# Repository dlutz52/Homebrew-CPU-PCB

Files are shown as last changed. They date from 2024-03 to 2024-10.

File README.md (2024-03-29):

# Homebrew CPU Project PCB

My inspiration for this PCB came from following Ian Ward's project on his web site:

[20xt6 Homebrew CPU Project](https://excess.org/cpu/)

This PCB implements the [LCD Character Display: Milestone 1 Complete!](https://www.youtube.com/watch?v=neW9uogt1gw) stage of this series of videos. 

But there is more to come in the future, so checkout Ian's videos on his future plans:

[Discrete Logic Rhythm Game Prototype (no CPU)](https://www.youtube.com/watch?v=yo5xX4GLc_U)

[Designing a Rhythm Game: Homebrew CPU Plan Step 2](https://www.youtube.com/watch?v=taPa7SQpib4)

[Maze Game Prototype (no CPU!)](https://www.youtube.com/shorts/fGyHHWiAYDM)

I will try to keep up with him.

PCB Front Image
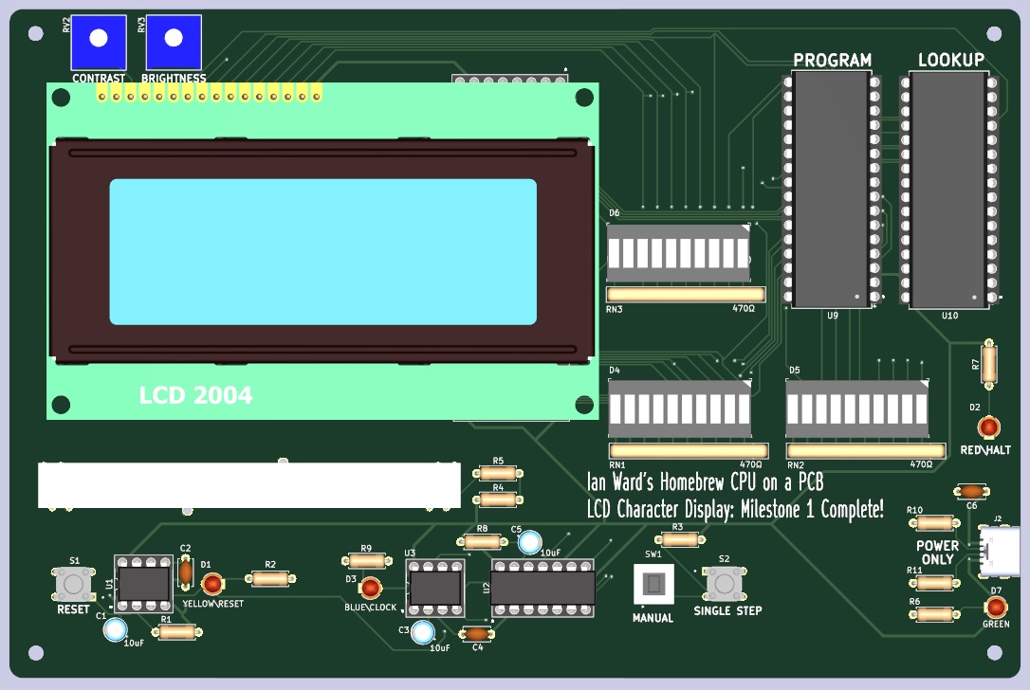
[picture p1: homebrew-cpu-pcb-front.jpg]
PCB Front Image


PCB Back Image
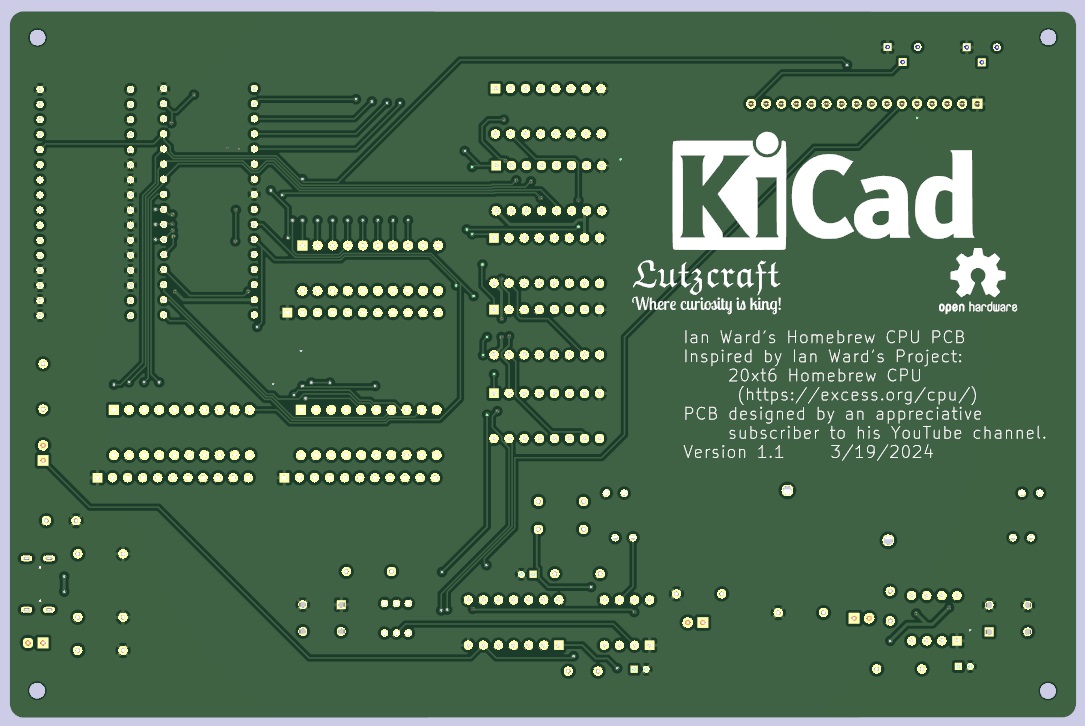
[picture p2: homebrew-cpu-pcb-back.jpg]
PCB Back Image


# Homebrew CPU PCB BOM

## Wed, Mar 21, 2024, 08:58:15

## Component Count: 25

Ref | Qty | Value | Vendor\Part # | Description
----|-----|-------|---------------|-----------
C1, C3, C5 | 3 | 10uF | Generic | Electrolytic capacitor
C2, C4, C6 | 2 | .01uF | Digikey\FG28C0G1H103JNT06 | Unpolarized capacitor 
D1 | 1 | YELLOW\Reset | Generic | LED\3mm\Yellow
D2 | 1 | RED\HALT | Generic | LED\3mm\Red 
D3 | 1 | BLUE\CLOCK | Generic | LED\3mm\Blue
D4, D5 | 2 | 10_SEG_LED BAR_GRAPH (Blue) | Digikey\1497-1079-5-ND | LED Bar Graph\Blue\1x10 
D6 | 1 | 10_SEG_LED  BAR_GRAPH (Yellow) | Digikey\754-1179-5-ND | LED Bar Graph\Yellow\1x10 
D7 | 1 | GREEN | Generic | LED\3mm\Green 
J1 | 1 | PinSocket_1x16_P2.54mm_Vertical | Generic | Female Pin Header\1x16\2.54mm pitch
J2 | 1 | UJC-HP-M-G-5-MSMT-TR | Digikey\2223-UJC-HP-M-G-5-MSMT-TRDKR-ND | Type C/20 VDC/3A/Horizontal/6 Pin/Power Only
R1, R3, R8 | 3 | 1Kohm | Digikey\13-MFR-25FTE52-1KCT-ND | Resistor\1Kohm\1%\1/4W\Axial
R2, R6, R7, R9 | 4 | 330ohm | Digikey\13-MFR-25FRF52-330RCT-ND | Resistor\330ohm\1%\1/4W\Axial
R4 | 1 | 220ohm | Generic | Resistor\220ohm\1%\1/4W\Axial
R5 | 1 | 3ohm | Generic | Resistor\3ohm\1%\1/4W\Axial
R10, R11 | 2 | 5.1Kohm | Digikey\13-MFR-25FTE52-5K1CT-ND | Resistor\5K1ohm\1%\1/4W\Axial
RN1, RN2, RN3 | 3 | 470ohm | Digikey\4609X-101-471LF-ND | Resistor Array\8 Resistors\470ohm\9SIP
RV1 | 1 | 10Kohm | Jameco\2276439 | Panasonic EWAQ30C15A14 Audio Slide Pot
RV2, RV3 | 2 | 5Kohm | Digikey\3386P-1-502LF | Trimmer Pot\5Kohms\0.5W\1/2W\Through Hole
SW1 | 1 | TL2230 | Digikey\EG6031-ND | Switch\Pushbutton\DPDT\Through Hole
S1 | 1 | REG SELECT | Digikey\450-1654-ND | Switch\Tactile\SPST-NO\0.05A\24V\Through Hole
S2 | 1 | ENABLE | Digikey\450-1654-ND | Switch\Tactile\SPST-NO\0.05A\24V\Through Hole
U1, U3 | 2 | LM555 | Digikey\LM555CNNS/NOPB-ND | 555 Timer/Oscillator\100kHz\8-PDIP
U2 | 1 | 74LS00 | Digikey\296-1626-ND | NAND Gate IC 4 Channel 14-PDIP
U4, U5, U6, U7, U8 | 5 | 74LS163 | Digikey\296-3661-5-ND | Binary Counter\4 Bit\Positive Edge\16-PDIP
U9, U10 | 2 | SST39SF040-70-4C-PHE | Digikey\SST39SF040-70-4C-PHE-ND | FLASH Memory\4Mbit\70ns\32-PDIP

The LCD and its 16-pin male header are represented only with 3D models, but you need a 2004 LCD with a soldered 16-pin male header with a pitch of 2.54mm to plug into the 16 pin female header to complete this PCB. I have found the best place to get these is on eBay.

Do NOT try to use a 2004 LCD with an I<sup>2</sup>C adapter on it.

Most symbols/footprints/models are contained under the 'libraries' directory. Capacitors, resistors and LEDs use KiCad symbols/footprints/models.

KiCad 7.0.10 was used to create this PCB. KiCad 8.0.1 is out now and this project opens in that version. The newer KiCad will warn that this project was created in previous version and will be saved in a the newer format. When closing the schematic or a PCB just discard any changes. If you do not you will not be able to use KiCad 7 any more without difficulties.

Models in KiCad's 3D view will display an appropriate socket under the ICs but these can be omitted on the PCB - they are used to make it easier to replace any components should they need it in the future. The only exceptions are the sockets for the SST39SF040 FLASH chips. These chips can be changed out for different program\lookup combinations, so you do not want to solder them to the PCB. I would recommend using 32-pin sockets from Aries Electronics or something equivalent, for example, Digikey\A410AE-ND.

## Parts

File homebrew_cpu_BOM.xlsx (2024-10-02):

# | Reference | Qty | Value | Footprint | Vendor\Part # | Vendor URL | Datasheet | Description
1 | C1, C3, C5 | 3 | 10µF | Capacitor_THT:CP_Radial_D4.0mm_P2.00mm | Generic |  |  | Electrolytic capacitor
2 | C2, C4, C6 | 2 | 0.01µF | Capacitor_THT:C_Disc_D4.7mm_W2.5mm_P5.00mm | Digikey\445-173474-1-ND | https://www.digikey.com/en/products/detail/tdk-corporation/FG28C0G1H103JNT06/5803088 | https://product.tdk.com/en/system/files | Unpolarized capacitor
3 | D1 | 1 | YELLOW\RESET | LED_THT:LED_D3.0mm | Generic |  |  | LED\3mm\Yellow
4 | D2 | 1 | RED\HALT | LED_THT:LED_D3.0mm | Generic |  |  | LED\3mm\Red
5 | D3 | 1 | BLUE\CLOCK | LED_THT:LED_D3.0mm | Generic |  |  | LED\3mm\Blue
6 | D4, D5 | 2 | LED_BAR_GRAPH 10_SEG | Homebrew-CPU-PCB:LED_Bar_Graph_10_SEG (Blue) | Digikey\1497-1079-5-ND | https://www.digikey.com/en/products/detail/sunled/XGCBDX10D/4745980 | https://www.sunledusa.com/products/spec/XGCBDX10D.pdf | LED Bar Graph\Blue\1x10
7 | D6 | 1 | LED_BAR_GRAPH 10_SEG | Homebrew-CPU-PCB:LED_Bar_Graph_10_SEG (Yellow) | Digikey\754-1179-5-ND | https://www.digikey.com/en/products/detail/kingbright/DC10YWA/1747578 | https://www.kingbrightusa.com/images/catalog/SPEC/DC10YWA.pdf | LED Bar Graph\Yellow\1x10
8 | D7 | 1 | GREEN\POWER | LED_THT:LED_D3.0mm | Generic |  |  | LED\3mm\Green
9 | J1 | 1 | LCD 2004 Female Header | Homebrew-CPU-PCB:LCD_2004_PinSocket_1x16_P2.54mm_Vertical | Generic |  |  | Female Pin Header\1x16\2.54mm pitch
10 | J2 | 1 | CUI_UJC-HP-M-G-5-MSMT-TR | Homebrew-CPU-PCB:CUI_UJC-HP-M-G-5-MSMT-TR | Digikey\2223-UJC-HP-M-G-5-MSMT-TRDKR-ND | https://www.digikey.com/en/products/detail/cui-devices/UJC-HP-M-G-5-MSMT-TR/16629543 | https://www.cuidevices.com/product/resource/ujc-hp-m-g-5-msmt-tr.pdf | Type C/20 VDC/3A/Horizontal/6 Pin/Power Only
11 | R1, R3, R8 | 3 | 1Kohm | Resistor_THT:R_Axial_DIN0207_L6.3mm_D2.5mm_P7.62mm_Horizontal | Digikey\13-MFR-25FTE52-1KCT-ND | https://www.digikey.com/en/products/detail/yageo/MFR-25FTE52-1K/9139842 | https://www.yageo.com/upload/media/product/app/datasheet/lr/yageo-mfr_datasheet.pdf | Resistor\1Kohm\1%\1/4W\Axial
12 | R2, R6, R7, R9 | 4 | 330ohm | Resistor_THT:R_Axial_DIN0207_L6.3mm_D2.5mm_P7.62mm_Horizontal | Digikey\13-MFR-25FRF52-330RCT-ND | https://www.digikey.com/en/products/detail/yageo/MFR-25FRF52-330R/9139001 | https://www.yageo.com/upload/media/product/app/datasheet/lr/yageo-mfr_datasheet.pdf | Resistor\330ohm\1%\1/4W\Axial
13 | R4 | 1 | 220ohm | Resistor_THT:R_Axial_DIN0207_L6.3mm_D2.5mm_P7.62mm_Horizontal | Generic |  |  | Resistor\220ohm\1%\1/4W\Axial
14 | R5 | 1 | 3ohm | Resistor_THT:R_Axial_DIN0207_L6.3mm_D2.5mm_P7.62mm_Horizontal | Generic |  |  | Resistor\3ohm\1%\1/4W\Axial
15 | R10, R11 | 2 | 5.1Kohm | Resistor_THT:R_Axial_DIN0207_L6.3mm_D2.5mm_P7.62mm_Horizontal | Digikey\13-MFR-25FTE52-5K1CT-ND | https://www.digikey.com/en/products/detail/yageo/MFR-25FTE52-5K1/9140307 | https://www.yageo.com/upload/media/product/app/datasheet/lr/yageo-mfr_datasheet.pdf | Resistor\5K1ohm\1%\1/4W\Axial
16 | RN1, RN2, RN3 | 3 | 470ohm | Homebrew-CPU-PCB:R_Array_SIP11 | Digikey\4609X-101-471LF-ND | https://www.digikey.com/en/products/detail/bourns-inc/4609X-101-471LF/3593678 | https://www.bourns.com/docs/Product-Datasheets/4600x.pdf | Resistor Array\8 Resistors\470ohm\9SIP
17 | RV1 | 1 | 10Kohm | Homebrew-CPU-PCB:10K_Audio_Slide_Pot | Jameco\2276439 | https://www.jameco.com/webapp/wcs/stores/servlet/ProductDisplay?productId=2276439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 | https://www.jameco.com/Jameco/Products/ProdDS/2276439.pdf | Panasonic EWAQ30C15A14 Audio Slide Pot
18 | RV2, RV3 | 2 | 3386P-1-502LF | Homebrew-CPU-PCB:BOURNE-3386P | Digikey\3386P-1-502LF | https://www.digikey.com/en/products/detail/bourns-inc/3386P-1-502LF/1088535 | https://www.bourns.com/docs/Product-Datasheets/3386.pdf | Trimmer Pot\5Kohms\0.5W\1/2W\Through Hole
19 | S1 | 1 | RESET | Homebrew-CPU-PCB:SW_1825967-1 | Digikey\450-1654-ND | https://www.digikey.com/en/products/detail/te-connectivity-alcoswitch-switches/1825967-1/1632540 | https://www.te.com/usa-en/product-1825967-1.datasheet.pdf | Switch\Tactile\SPST-NO\0.05A\24V\Through Hole
20 | S2 | 1 | SINGLE STEP | Homebrew-CPU-PCB:SW_1825967-1 | Digikey\450-1654-ND | https://www.digikey.com/en/products/detail/te-connectivity-alcoswitch-switches/1825967-1/1632540 | https://www.te.com/usa-en/product-1825967-1.datasheet.pdf | Switch\Tactile\SPST-NO\0.05A\24V\Through Hole
21 | SW1 | 1 | TL2230 | Homebrew-CPU-PCB:TL2230EEF140 | Digikey\EG6031-ND | https://www.digikey.com/en/products/detail/e-switch/TL2230EEF140/4029358 | https://eswitch.wpengine.com/wp-content/uploads/2022/06/TL2201-3.pdf | Switch\Pushbutton\DPDT\Through Hole
22 | U1, U3 | 2 | LM555 | Homebrew-CPU-PCB:DIP-8_W7.62mm_Socket | Digikey\LM555CNNS/NOPB-ND | https://www.digikey.com/en/products/detail/texas-instruments/LM555CN-NOPB/6575 | https://www.ti.com/lit/ds/symlink/lm555.pdf | 555 Timer/Oscillator\100kHz\8-PDIP
23 | U2 | 1 | 74LS00 | Homebrew-CPU-PCB:DIP-14_W7.62mm_Socket | Digikey\296-1626-ND | https://www.digikey.com/en/products/detail/texas-instruments/SN74LS00N/277272 | https://www.ti.com/lit/ds/symlink/sn7400.pdf | NAND Gate IC 4 Channel 14-PDI
24 | U4, U5, U6, U7, U8 | 5 | 74LS163 | Homebrew-CPU-PCB:DIP-16_W7.62mm_Socket | Digikey\296-3661-5-ND | https://www.digikey.com/en/products/detail/texas-instruments/SN74LS163AN/377784 | https://www.ti.com/lit/ds/symlink/sn74ls163a.pdf | Binary Counter\4 Bit\Positive Edge\16-PDIP
25 | U9, U10 | 2 | SST39SF040-70-4C-PHE | Homebrew-CPU-PCB:PDIP32_PH_SST_MCH | Digikey\SST39SF040-70-4C-PHE-ND | https://www.digikey.com/en/products/detail/microchip-technology/SST39SF040-70-4C-PHE/2297835 | https://ww1.microchip.com/downloads/en/DeviceDoc/20005022C.pdf | FLASH Memory\4Mbit\70ns\32-PDIP

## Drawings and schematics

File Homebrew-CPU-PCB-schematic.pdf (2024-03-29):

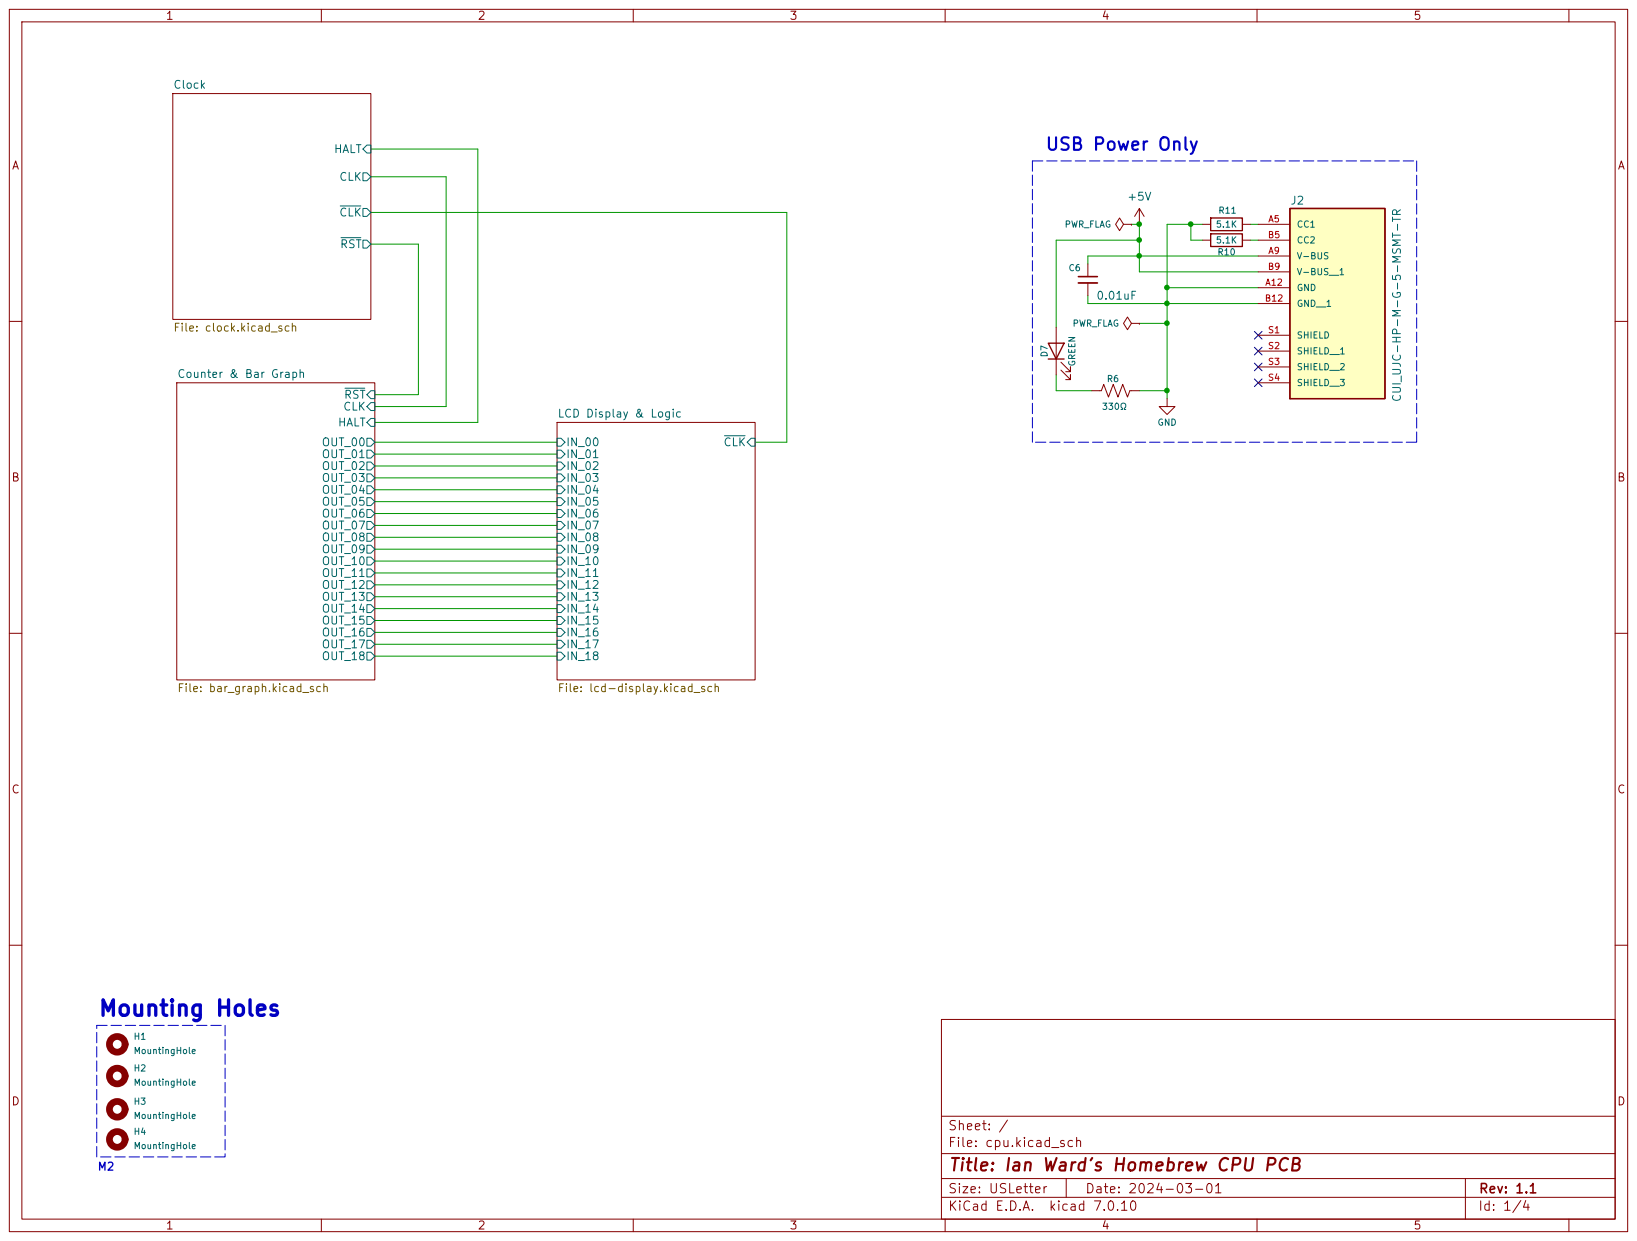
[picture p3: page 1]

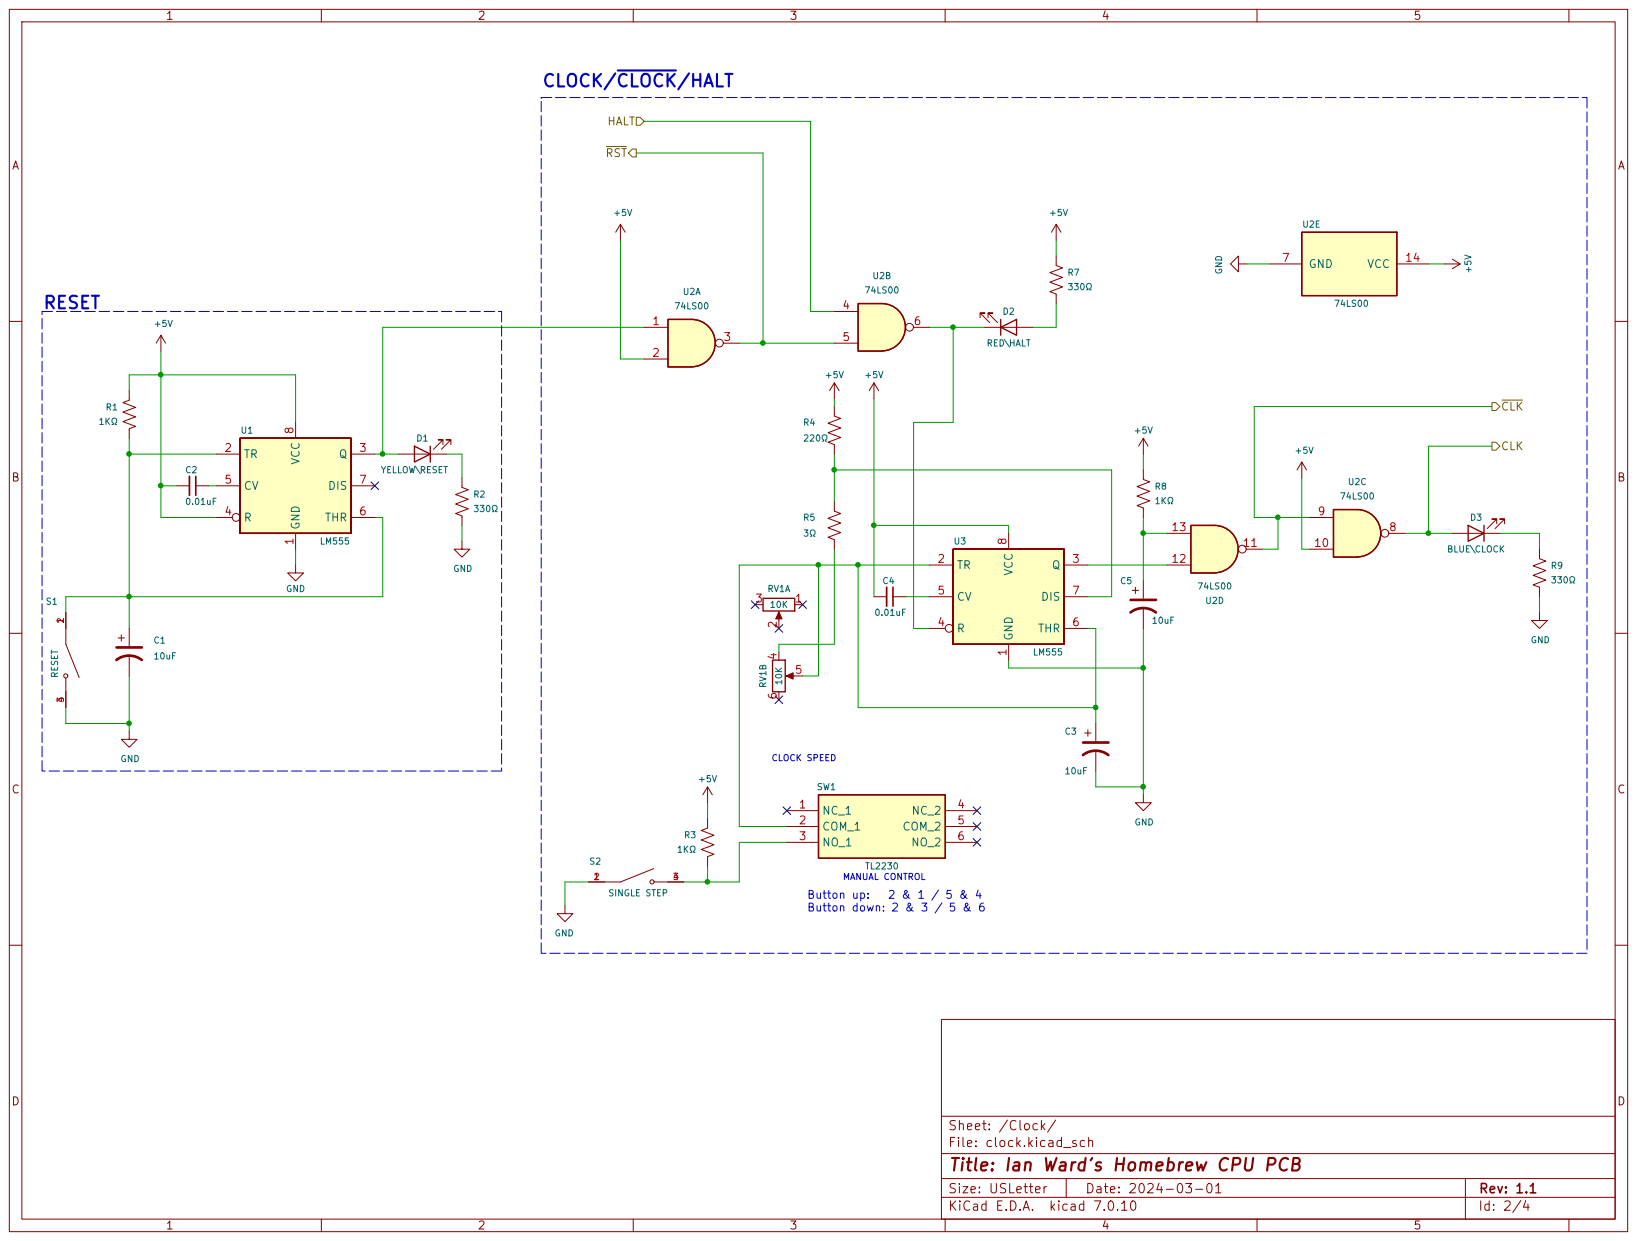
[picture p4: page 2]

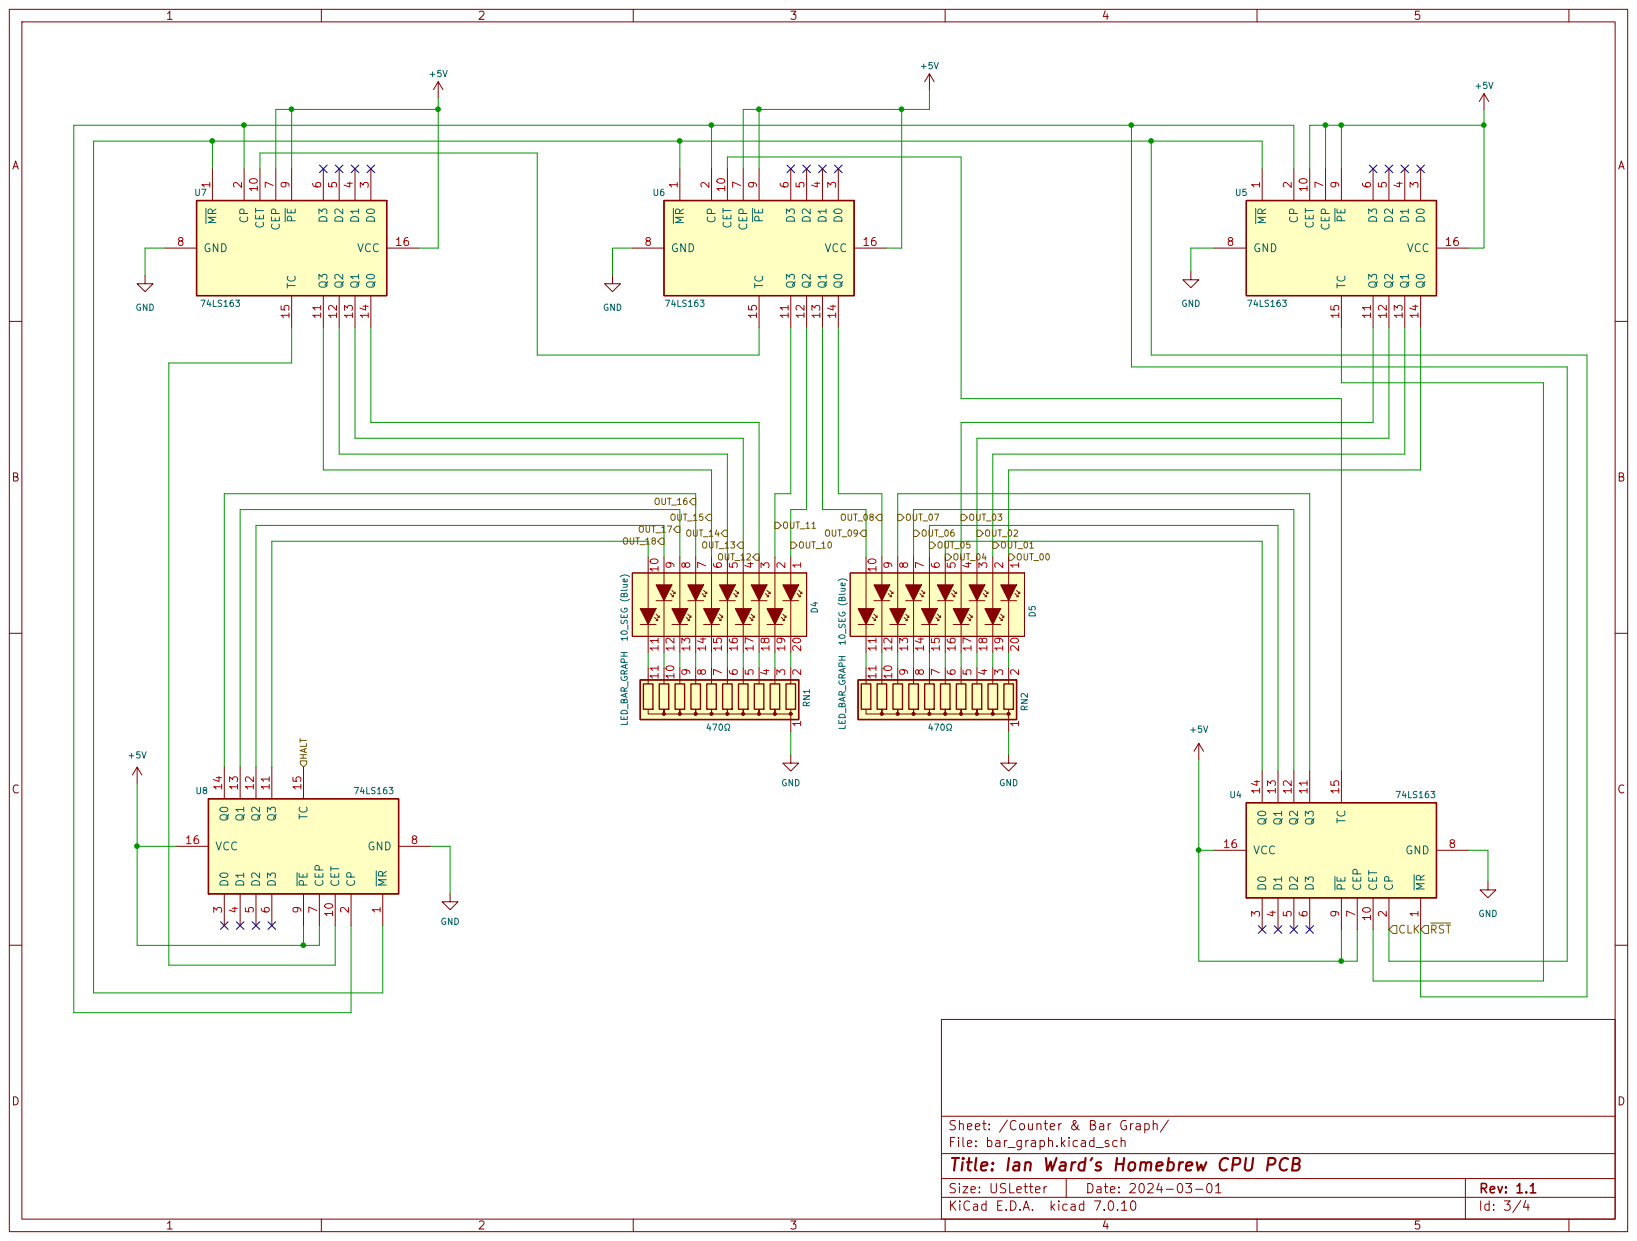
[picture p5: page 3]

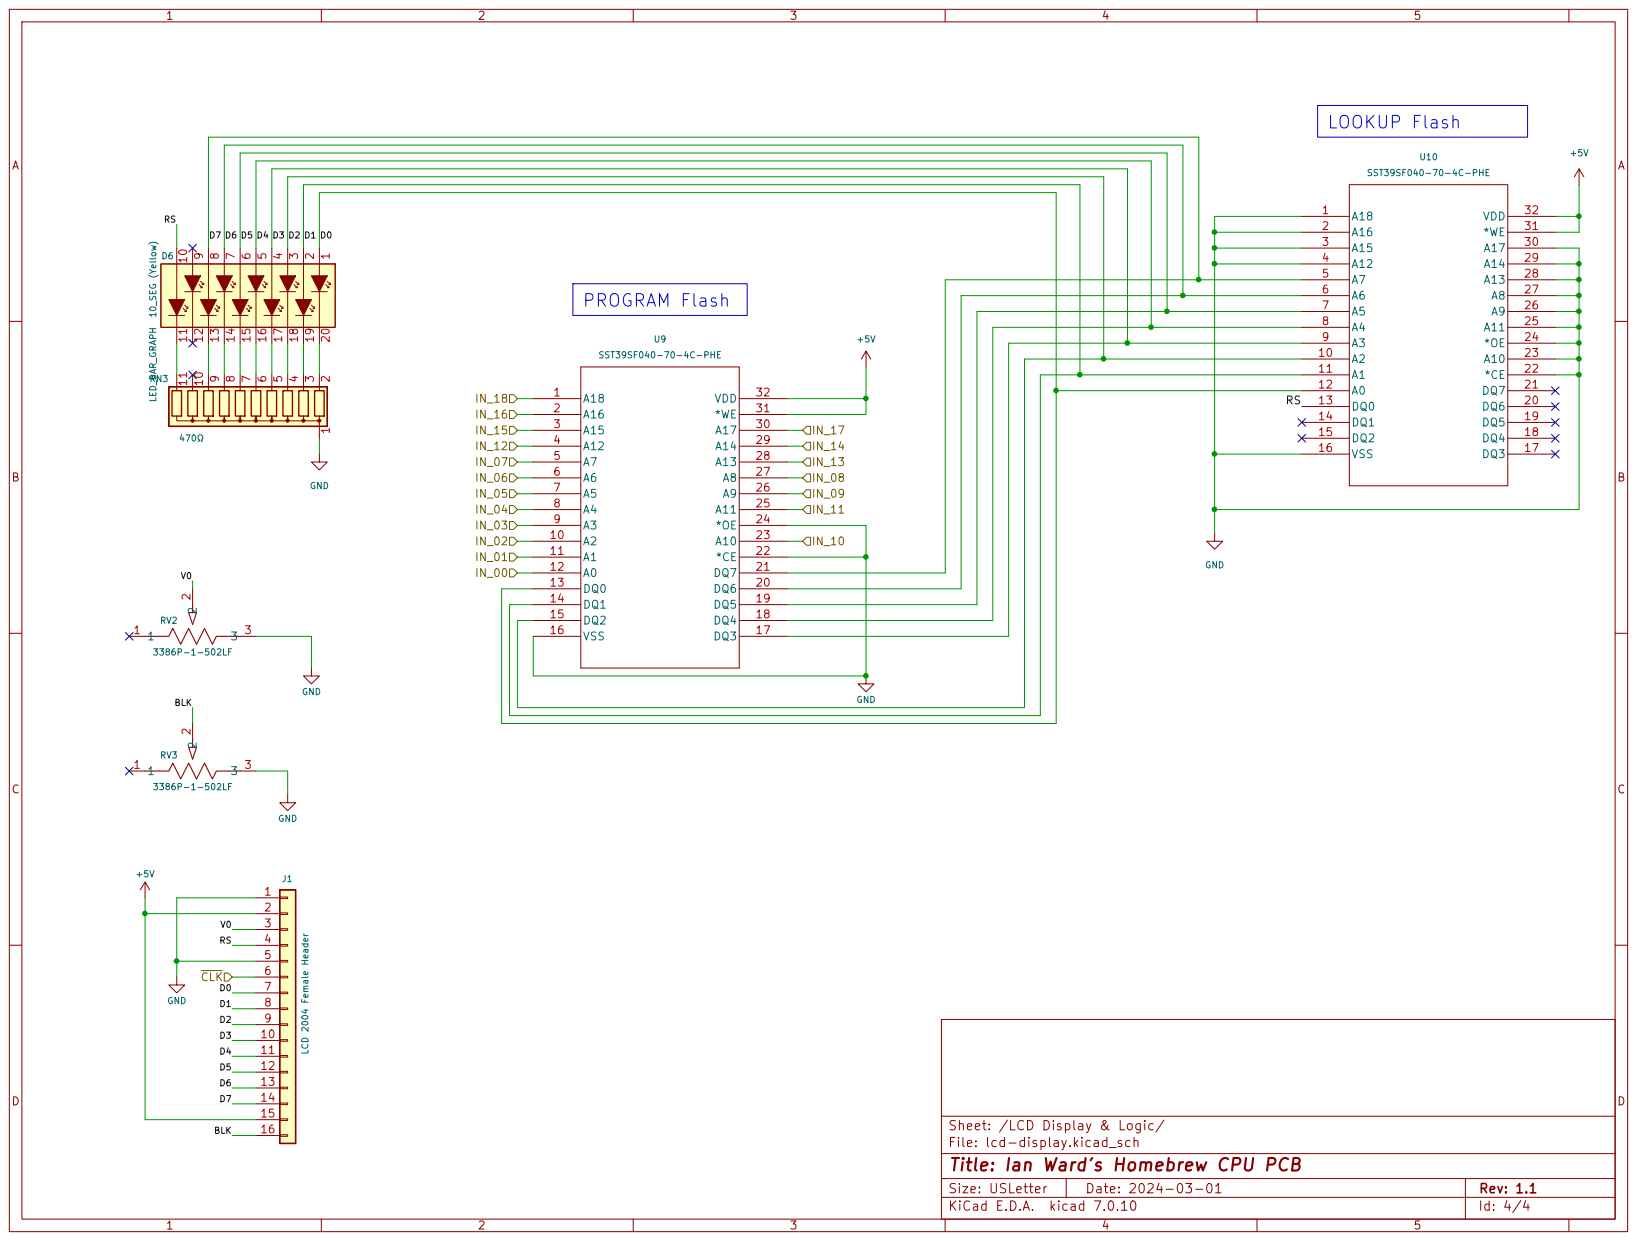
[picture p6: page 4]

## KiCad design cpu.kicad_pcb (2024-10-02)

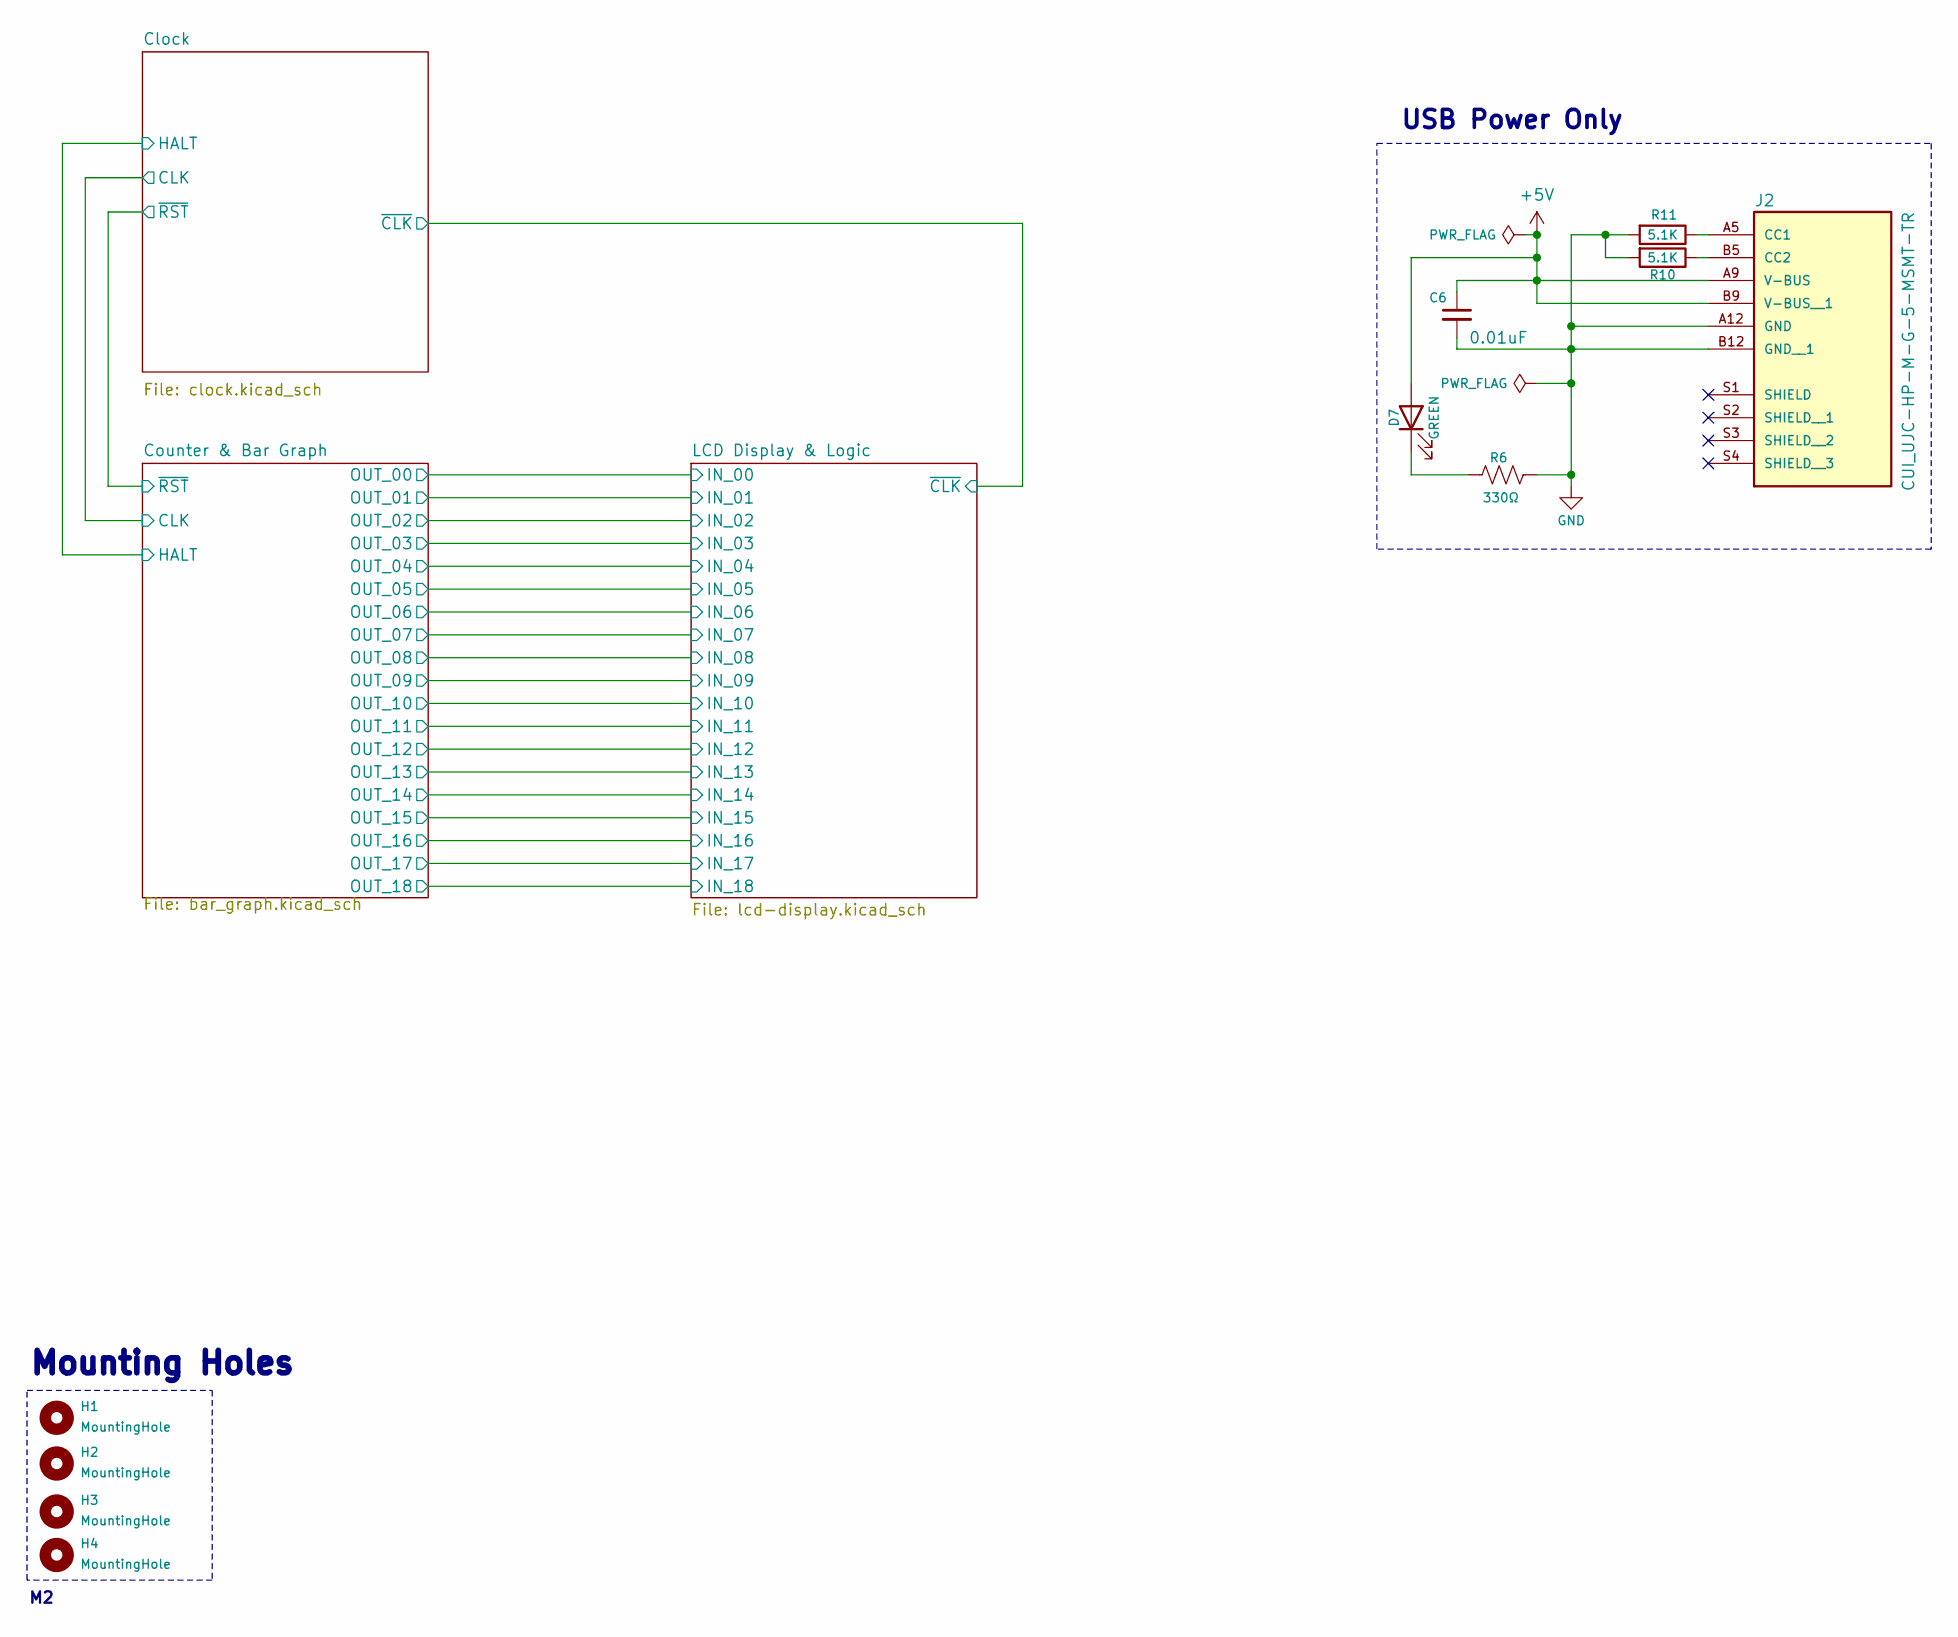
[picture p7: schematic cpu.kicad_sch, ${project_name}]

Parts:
C6: 0.01uF; C_Disc_D4.7mm_W2.5mm_P5.00mm
D7: GREEN; LED_D3.0mm
H1, H2, H3, H4: MountingHole; MountingHole_2.7mm_M2.5
J2: CUI_UJC-HP-M-G-5-MSMT-TR; PARTREV 04/30/2020
R6: 330Ω; R_Axial_DIN0207_L6.3mm_D2.5mm_P7.62mm_Horizontal
R10, R11: 5.1K; R_Axial_DIN0207_L6.3mm_D2.5mm_P7.62mm_Horizontal

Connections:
+5V: C6.1, D7.2 (A), J2.A9 (V-BUS), J2.B9 (V-BUS__1); also elsewhere on the board
GND: C6.2, J2.A12 (GND), J2.B12 (GND__1), R6.1, R10.2, R11.2; also elsewhere on the board
unnamed: D7.1 (K), R6.2
unnamed: J2.A5 (CC1), R11.1
unnamed: J2.B5 (CC2), R10.1

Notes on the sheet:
Mounting Holes
USB Power Only

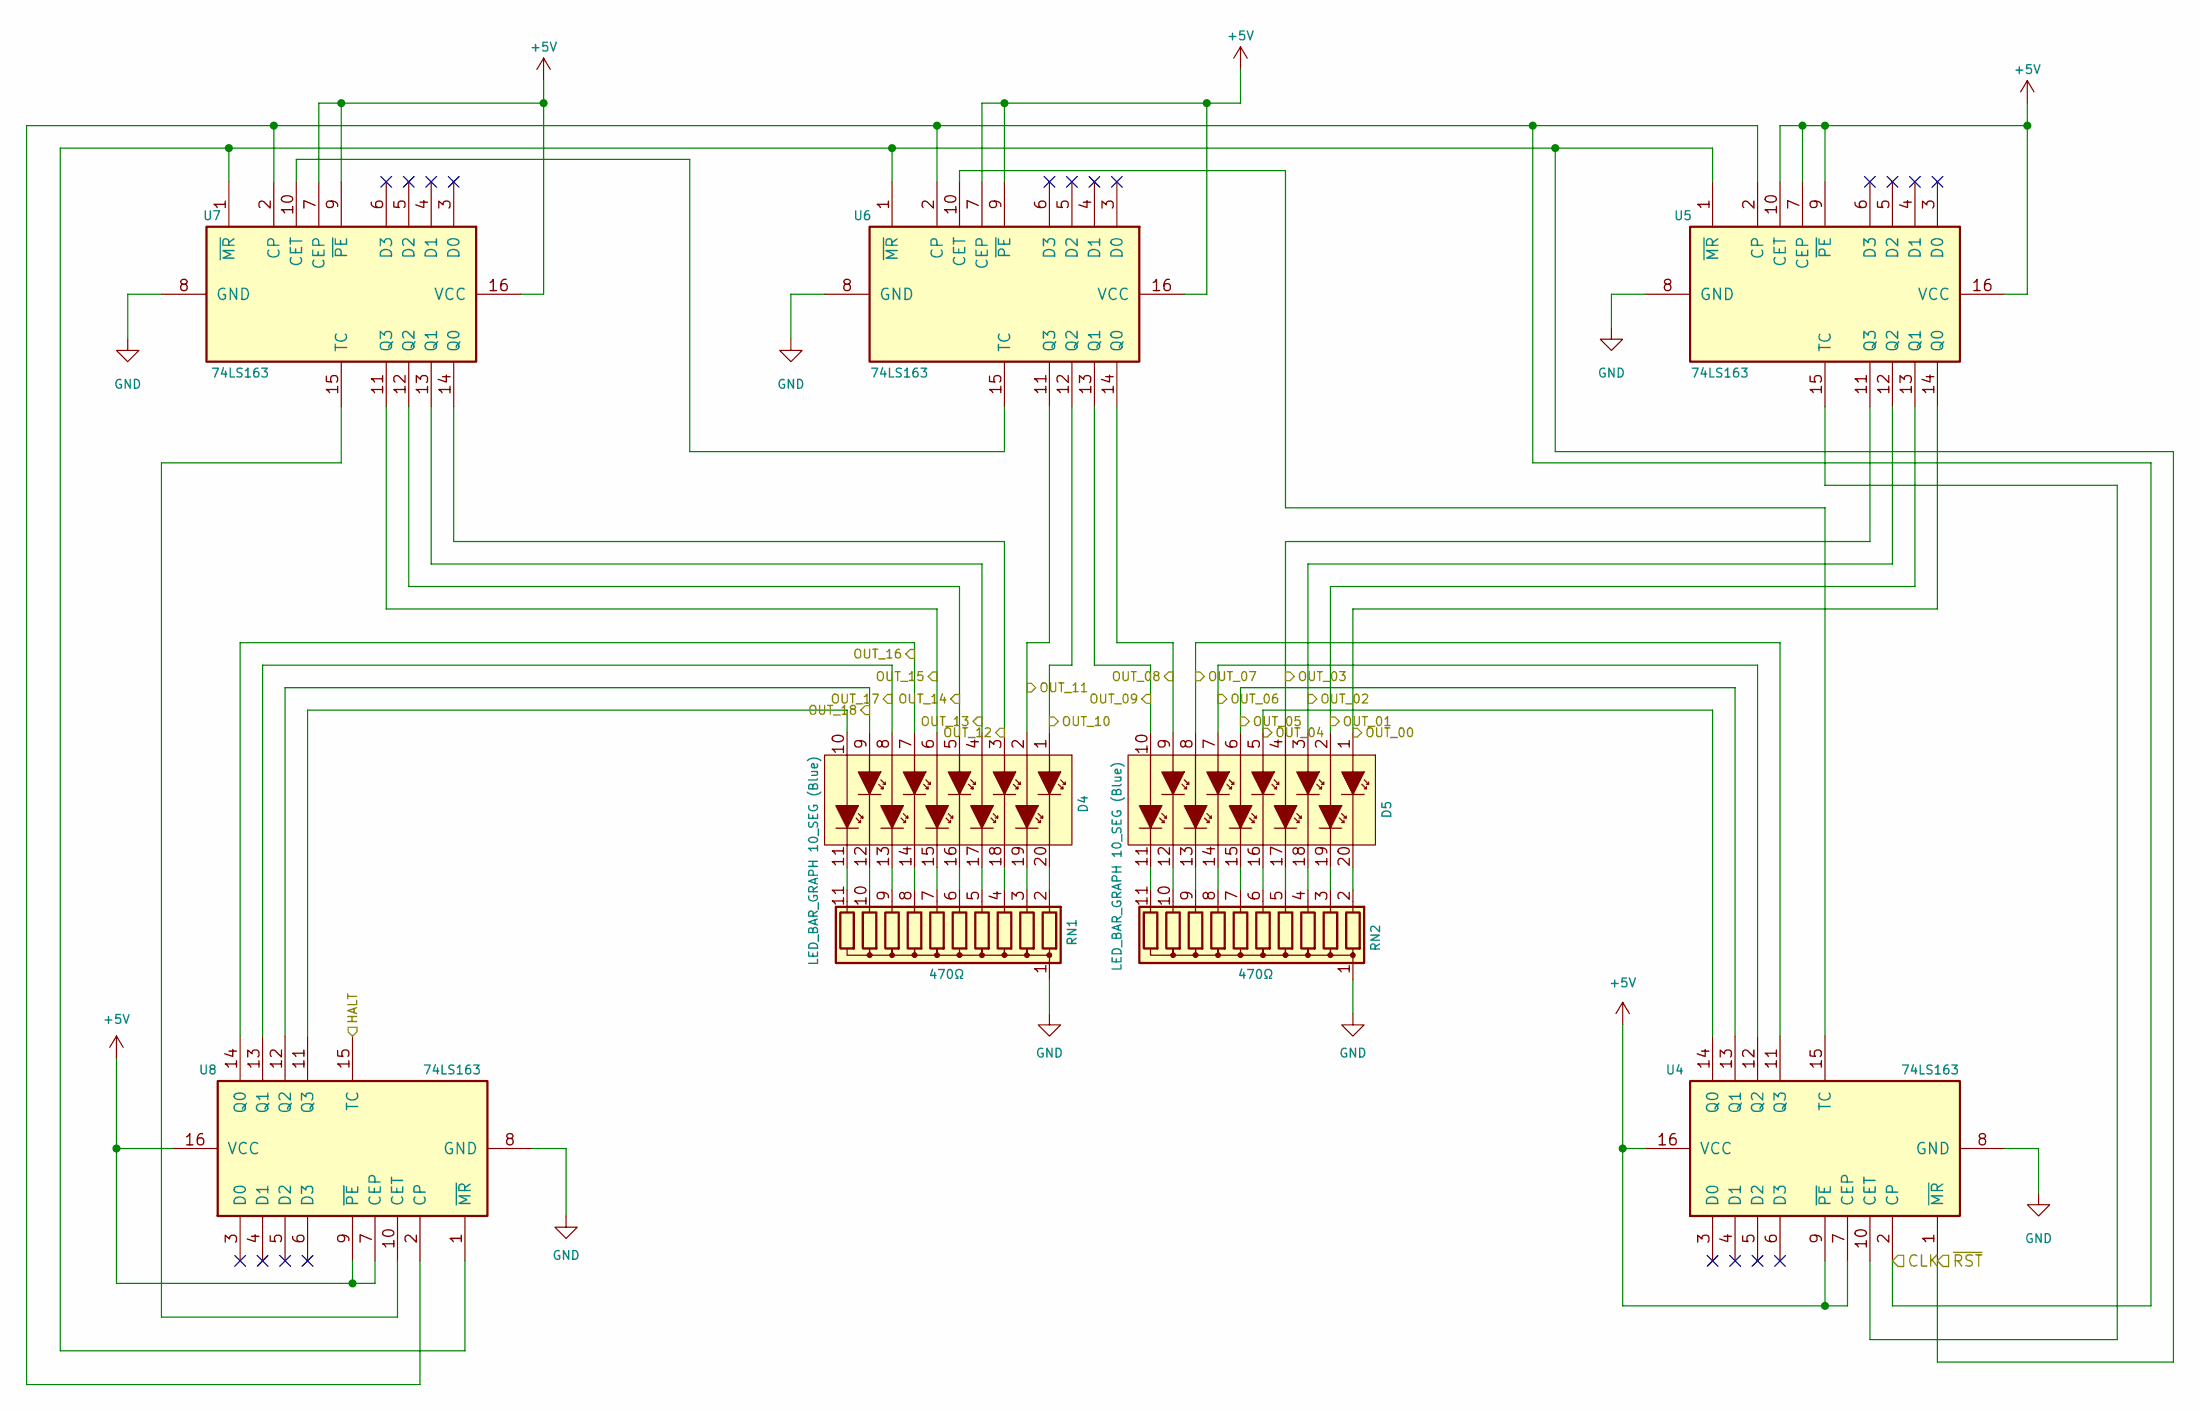
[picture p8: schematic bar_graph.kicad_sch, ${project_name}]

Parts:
D4, D5: LED_BAR_GRAPH 10_SEG (Blue); LED_Bar_Graph_10_SEG
RN1, RN2: 470Ω; R_Array_SIP11
U4, U5, U6, U7, U8: 74LS163; DIP-16_W7.62mm_Socket

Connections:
+5V: U4.7 (CEP), U4.9 (~PE), U4.16 (VCC), U5.7 (CEP), U5.9 (~PE), U5.10 (CET), U5.16 (VCC), U6.7 (CEP), U6.9 (~PE), U6.16 (VCC), U7.7 (CEP), U7.9 (~PE), U7.16 (VCC), U8.7 (CEP), U8.9 (~PE), U8.16 (VCC); also elsewhere on the board
/Clock/CLK: U4.2 (CP), U5.2 (CP), U6.2 (CP), U7.2 (CP), U8.2 (CP); also elsewhere on the board
/Clock/HALT: U8.15 (TC); also elsewhere on the board
/Clock/~RST: U4.1 (~MR), U5.1 (~MR), U6.1 (~MR), U7.1 (~MR), U8.1 (~MR); also elsewhere on the board
/Counter & Bar Graph/OUT_00: D5.1, U5.14 (Q0); also elsewhere on the board
/Counter & Bar Graph/OUT_01: D5.2, U5.13 (Q1); also elsewhere on the board
/Counter & Bar Graph/OUT_02: D5.3, U5.12 (Q2); also elsewhere on the board
/Counter & Bar Graph/OUT_03: D5.4, U5.11 (Q3); also elsewhere on the board
/Counter & Bar Graph/OUT_04: D5.5, U4.14 (Q0); also elsewhere on the board
/Counter & Bar Graph/OUT_05: D5.6, U4.13 (Q1); also elsewhere on the board
/Counter & Bar Graph/OUT_06: D5.7, U4.12 (Q2); also elsewhere on the board
/Counter & Bar Graph/OUT_07: D5.8, U4.11 (Q3); also elsewhere on the board
/Counter & Bar Graph/OUT_08: D5.9, U6.14 (Q0); also elsewhere on the board
/Counter & Bar Graph/OUT_09: D5.10, U6.13 (Q1); also elsewhere on the board
/Counter & Bar Graph/OUT_10: D4.1, U6.12 (Q2); also elsewhere on the board
/Counter & Bar Graph/OUT_11: D4.2, U6.11 (Q3); also elsewhere on the board
/Counter & Bar Graph/OUT_12: D4.3, U7.14 (Q0); also elsewhere on the board
/Counter & Bar Graph/OUT_13: D4.4, U7.13 (Q1); also elsewhere on the board
/Counter & Bar Graph/OUT_14: D4.5, U7.12 (Q2); also elsewhere on the board
/Counter & Bar Graph/OUT_15: D4.6, U7.11 (Q3); also elsewhere on the board
/Counter & Bar Graph/OUT_16: D4.7, U8.14 (Q0); also elsewhere on the board
/Counter & Bar Graph/OUT_17: D4.8, U8.13 (Q1); also elsewhere on the board
/Counter & Bar Graph/OUT_18: D4.9, U8.12 (Q2); also elsewhere on the board
GND: RN1.1 (common), RN2.1 (common), U4.8 (GND), U5.8 (GND), U6.8 (GND), U7.8 (GND), U8.8 (GND); also elsewhere on the board
unnamed: D4.20, RN1.2 (R1)
unnamed: D4.19, RN1.3 (R2)
unnamed: D4.18, RN1.4 (R3)
unnamed: D4.17, RN1.5 (R4)
unnamed: D4.16, RN1.6 (R5)
unnamed: D4.15, RN1.7 (R6)
unnamed: D4.14, RN1.8 (R7)
unnamed: D4.13, RN1.9 (R8)
unnamed: D4.12, RN1.10 (R9)
unnamed: D4.11, RN1.11 (R10)
unnamed: D5.20, RN2.2 (R1)
unnamed: D5.19, RN2.3 (R2)
unnamed: D5.18, RN2.4 (R3)
unnamed: D5.17, RN2.5 (R4)
unnamed: D5.16, RN2.6 (R5)
unnamed: D5.15, RN2.7 (R6)
unnamed: D5.14, RN2.8 (R7)
unnamed: D5.13, RN2.9 (R8)
unnamed: D5.12, RN2.10 (R9)
unnamed: D5.11, RN2.11 (R10)
unnamed: U4.10 (CET), U5.15 (TC)
unnamed: U4.15 (TC), U6.10 (CET)
unnamed: U6.15 (TC), U7.10 (CET)
unnamed: U7.15 (TC), U8.10 (CET)
unnamed: D4.10, U8.11 (Q3)

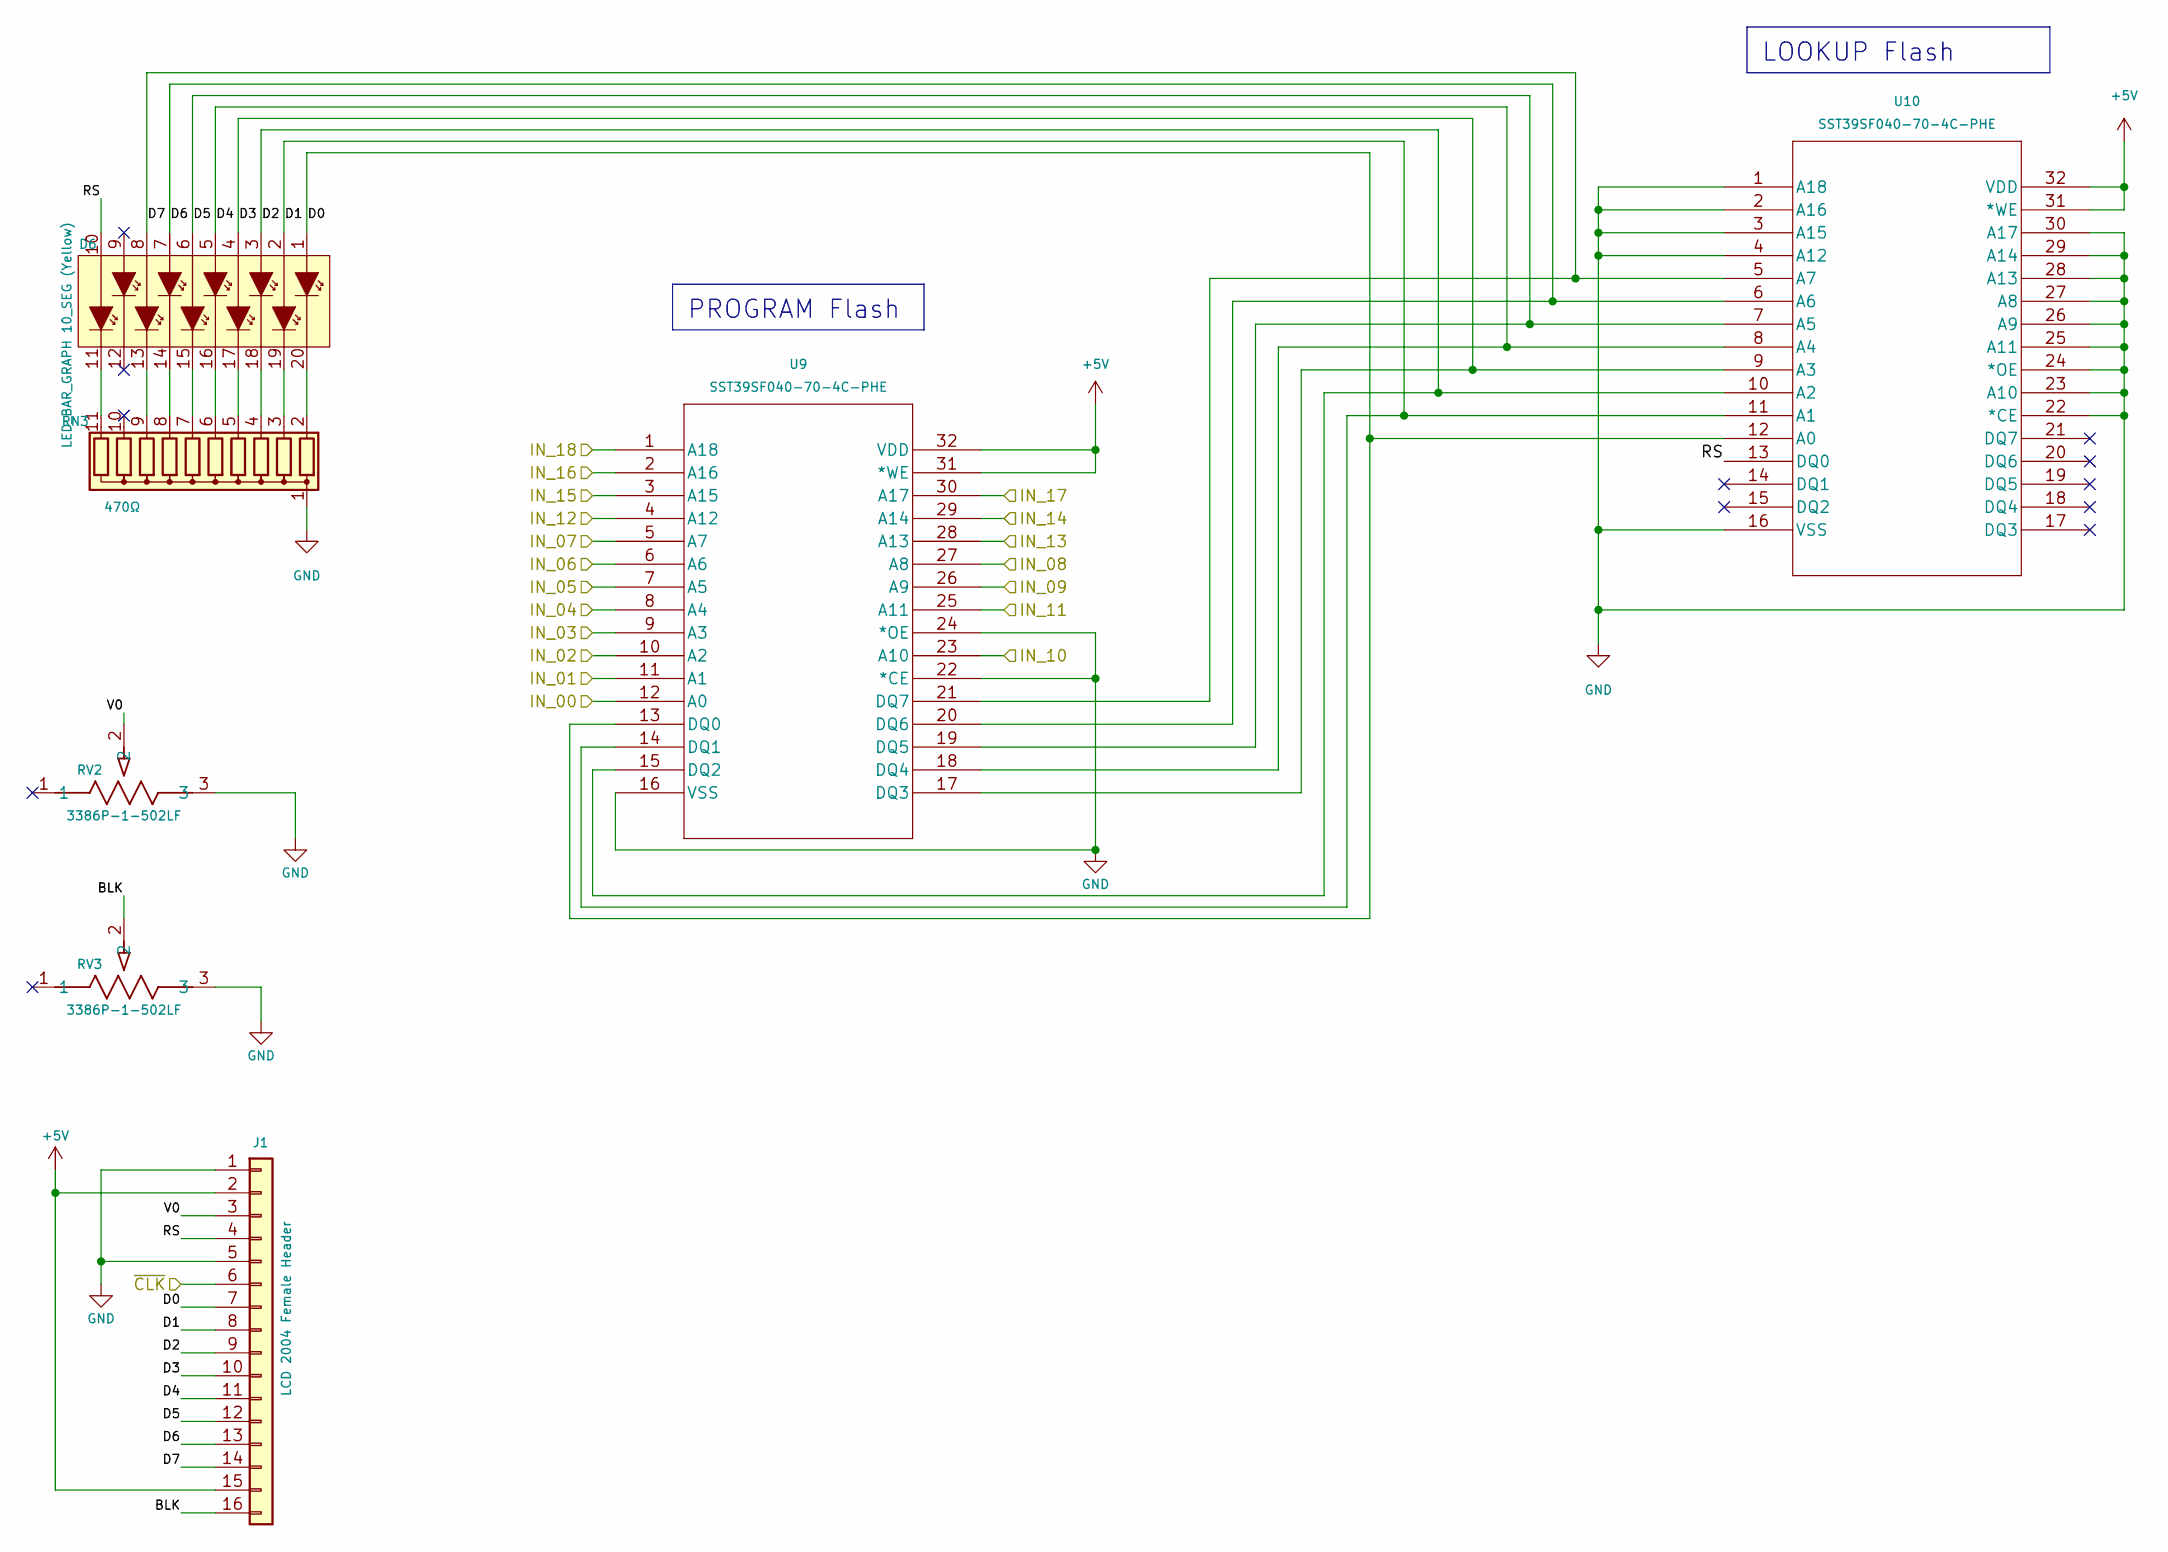
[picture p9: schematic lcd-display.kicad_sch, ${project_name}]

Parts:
D6: LED_BAR_GRAPH 10_SEG (Yellow); LED_Bar_Graph_10_SEG
J1: LCD 2004 Female Header; LCD_2004_PinSocket_1x16_P2.54mm_Vertical
RN3: 470Ω; R_Array_SIP11
RV2, RV3: 3386P-1-502LF; BOURNE-3386P; Digikey PN 3386P-502LF-ND
U9, U10: SST39SF040-70-4C-PHE; PDIP32_PH_SST_MCH

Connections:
+5V: J1.2, J1.15, U9.31 (*WE), U9.32 (VDD), U10.31 (*WE), U10.32 (VDD); also elsewhere on the board
/Clock/~CLK: J1.6; also elsewhere on the board
/Counter & Bar Graph/OUT_00: U9.12 (A0); also elsewhere on the board
/Counter & Bar Graph/OUT_01: U9.11 (A1); also elsewhere on the board
/Counter & Bar Graph/OUT_02: U9.10 (A2); also elsewhere on the board
/Counter & Bar Graph/OUT_03: U9.9 (A3); also elsewhere on the board
/Counter & Bar Graph/OUT_04: U9.8 (A4); also elsewhere on the board
/Counter & Bar Graph/OUT_05: U9.7 (A5); also elsewhere on the board
/Counter & Bar Graph/OUT_06: U9.6 (A6); also elsewhere on the board
/Counter & Bar Graph/OUT_07: U9.5 (A7); also elsewhere on the board
/Counter & Bar Graph/OUT_08: U9.27 (A8); also elsewhere on the board
/Counter & Bar Graph/OUT_09: U9.26 (A9); also elsewhere on the board
/Counter & Bar Graph/OUT_10: U9.23 (A10); also elsewhere on the board
/Counter & Bar Graph/OUT_11: U9.25 (A11); also elsewhere on the board
/Counter & Bar Graph/OUT_12: U9.4 (A12); also elsewhere on the board
/Counter & Bar Graph/OUT_13: U9.28 (A13); also elsewhere on the board
/Counter & Bar Graph/OUT_14: U9.29 (A14); also elsewhere on the board
/Counter & Bar Graph/OUT_15: U9.3 (A15); also elsewhere on the board
/Counter & Bar Graph/OUT_16: U9.2 (A16); also elsewhere on the board
/Counter & Bar Graph/OUT_17: U9.30 (A17); also elsewhere on the board
/Counter & Bar Graph/OUT_18: U9.1 (A18); also elsewhere on the board
/LCD Display & Logic/BLK: J1.16, RV3.2
/LCD Display & Logic/D0: D6.1, J1.7, U9.13 (DQ0), U10.12 (A0)
/LCD Display & Logic/D1: D6.2, J1.8, U9.14 (DQ1), U10.11 (A1)
/LCD Display & Logic/D2: D6.3, J1.9, U9.15 (DQ2), U10.10 (A2)
/LCD Display & Logic/D3: D6.4, J1.10, U9.17 (DQ3), U10.9 (A3)
/LCD Display & Logic/D4: D6.5, J1.11, U9.18 (DQ4), U10.8 (A4)
/LCD Display & Logic/D5: D6.6, J1.12, U9.19 (DQ5), U10.7 (A5)
/LCD Display & Logic/D6: D6.7, J1.13, U9.20 (DQ6), U10.6 (A6)
/LCD Display & Logic/D7: D6.8, J1.14, U9.21 (DQ7), U10.5 (A7)
/LCD Display & Logic/RS: D6.10, J1.4, U10.13 (DQ0)
/LCD Display & Logic/V0: J1.3, RV2.2
GND: J1.1, J1.5, RN3.1 (common), RV2.3, RV3.3, U9.16 (VSS), U9.22 (*CE), U9.24 (*OE), U10.1 (A18), U10.2 (A16), U10.3 (A15), U10.4 (A12), U10.16 (VSS), U10.22 (*CE), U10.23 (A10), U10.24 (*OE), U10.25 (A11), U10.26 (A9), U10.27 (A8), U10.28 (A13), U10.29 (A14), U10.30 (A17); also elsewhere on the board
unnamed: D6.20, RN3.2 (R1)
unnamed: D6.19, RN3.3 (R2)
unnamed: D6.18, RN3.4 (R3)
unnamed: D6.17, RN3.5 (R4)
unnamed: D6.16, RN3.6 (R5)
unnamed: D6.15, RN3.7 (R6)
unnamed: D6.14, RN3.8 (R7)
unnamed: D6.13, RN3.9 (R8)
unnamed: D6.11, RN3.11 (R10)

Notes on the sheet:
LOOKUP Flash
PROGRAM Flash

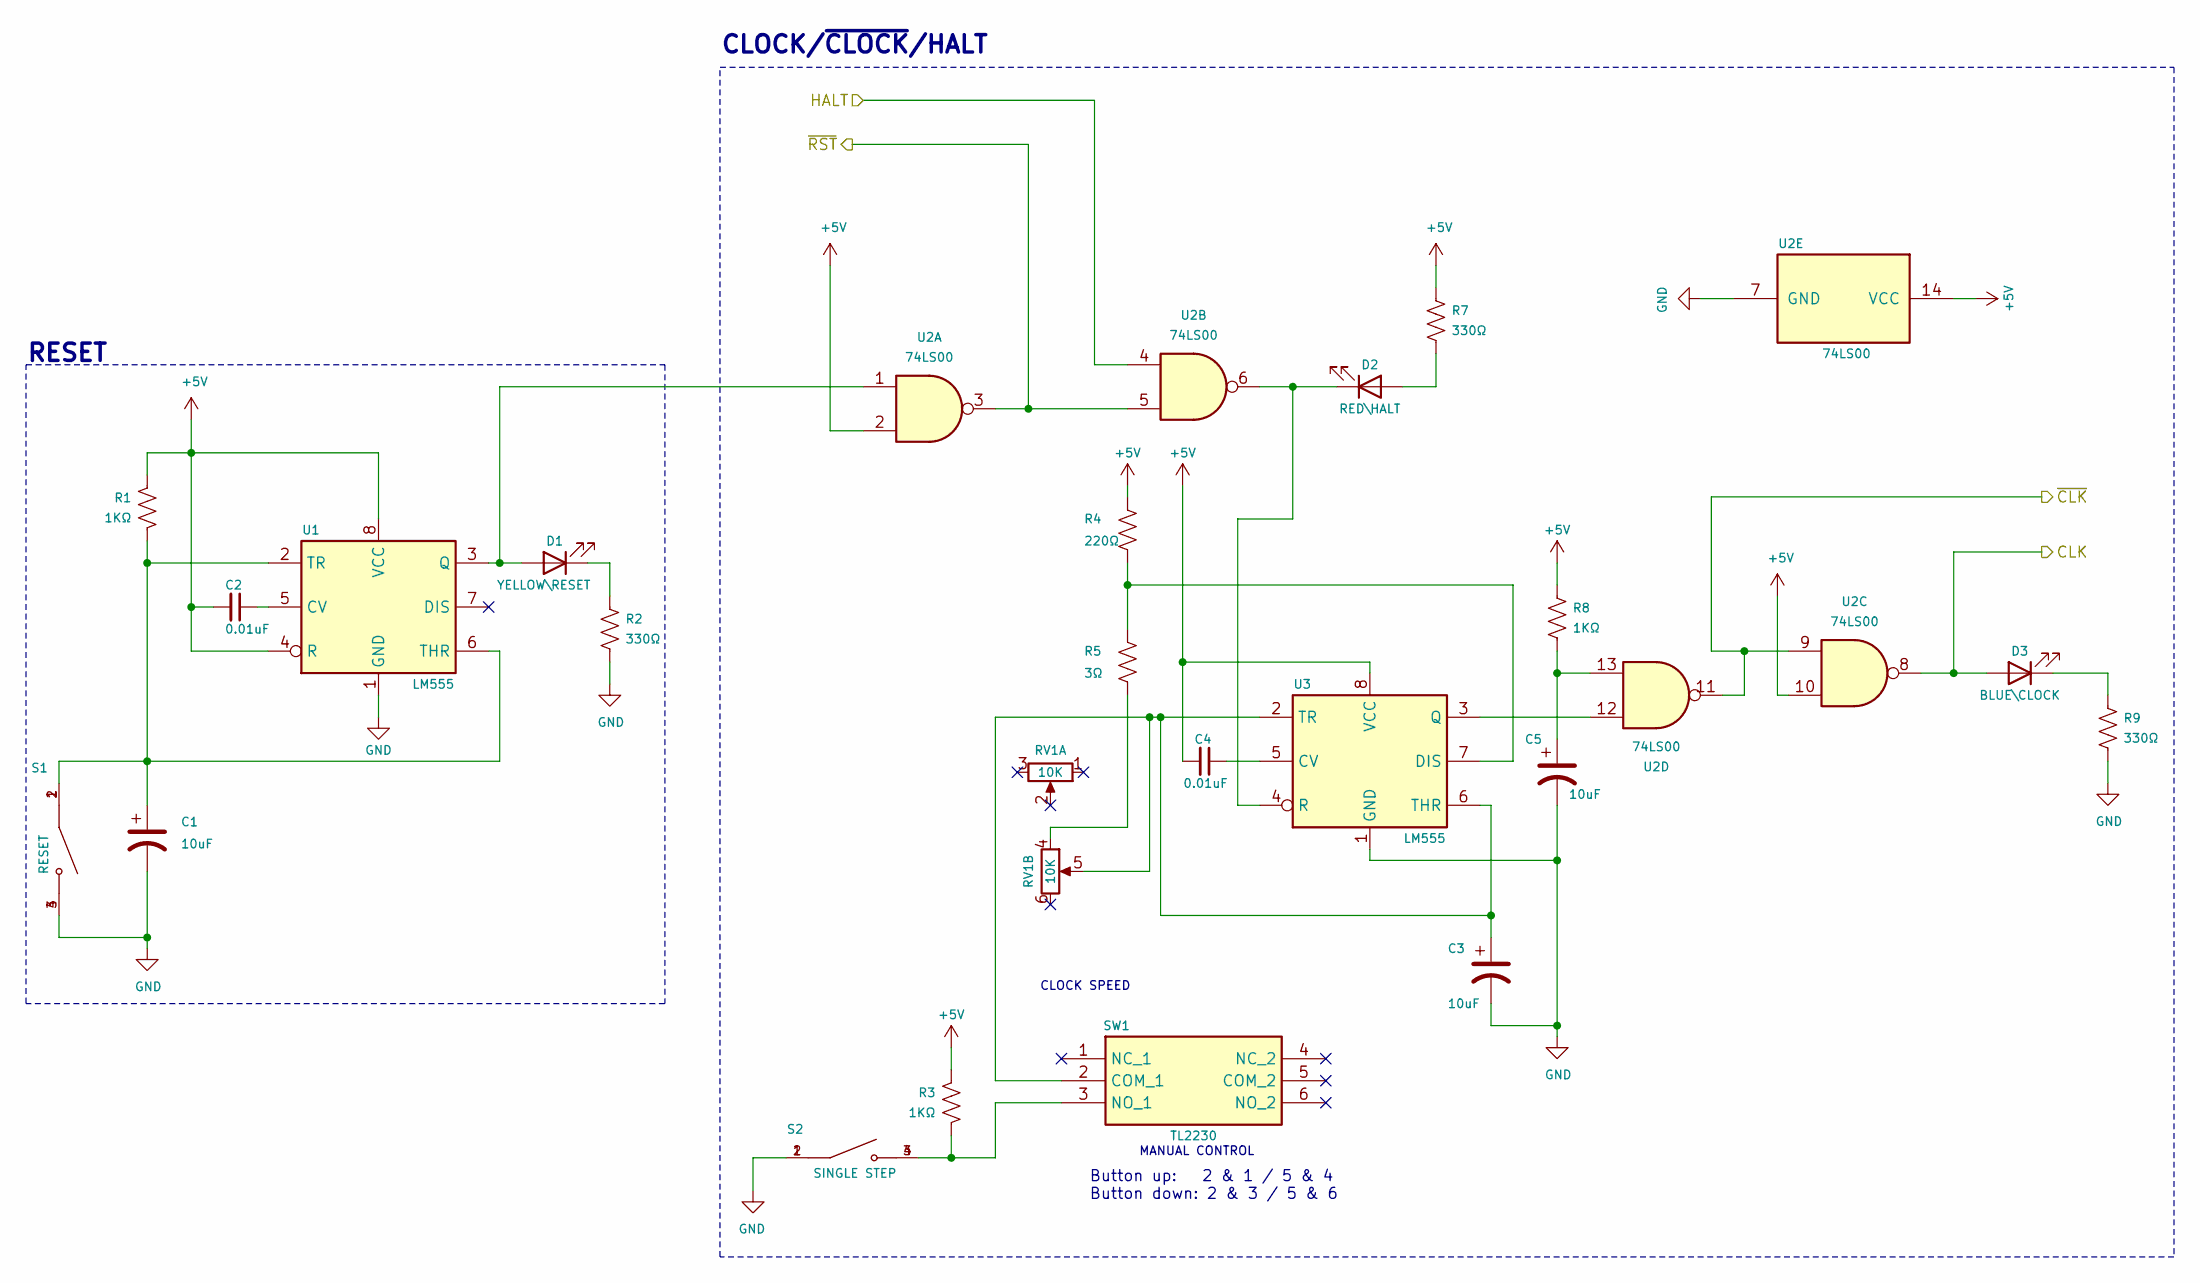
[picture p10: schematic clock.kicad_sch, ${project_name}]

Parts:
C1, C3, C5: 10uF; CP_Radial_D4.0mm_P2.00mm
C2, C4: 0.01uF; C_Disc_D4.7mm_W2.5mm_P5.00mm
D1: YELLOW\RESET; LED_D3.0mm
D2: RED\HALT; LED_D3.0mm
D3: BLUE\CLOCK; LED_D3.0mm
R1, R3, R8: 1KΩ; R_Axial_DIN0207_L6.3mm_D2.5mm_P7.62mm_Horizontal
R2, R7, R9: 330Ω; R_Axial_DIN0207_L6.3mm_D2.5mm_P7.62mm_Horizontal
R4: 220Ω; R_Axial_DIN0207_L6.3mm_D2.5mm_P7.62mm_Horizontal
R5: 3Ω; R_Axial_DIN0207_L6.3mm_D2.5mm_P7.62mm_Horizontal
RV1: 10K; 10K_Audio_Slide_Pot
S1: RESET; SW_1825967-1
S2: SINGLE STEP; SW_1825967-1
SW1: TL2230; TL2230EEF140; Mouser Part Number 612-TL2230EEF140
U1, U3: LM555; DIP-8_W7.62mm_Socket
U2: 74LS00; DIP-14_W7.62mm_Socket

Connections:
+5V: C2.2, C4.2, R1.1, R3.1, R4.1, R7.2, R8.1, U1.4 (R), U1.8 (VCC), U2.2, U2.10, U2.14 (VCC), U3.8 (VCC); also elsewhere on the board
/Clock/CLK: D3.2 (A), U2.8; also elsewhere on the board
/Clock/HALT: U2.4; also elsewhere on the board
/Clock/~CLK: U2.9, U2.11; also elsewhere on the board
/Clock/~RST: U2.3, U2.5; also elsewhere on the board
GND: C1.2, C3.2, C5.2, R2.1, R9.1, S1.3, S1.4, S2.1, S2.2, U1.1 (GND), U2.7 (GND), U3.1 (GND); also elsewhere on the board
unnamed: C5.1, R8.2, U2.13
unnamed: D1.2 (A), U1.3 (Q), U2.1
unnamed: D1.1 (K), R2.2
unnamed: D2.2 (A), R7.1
unnamed: D2.1 (K), U2.6, U3.4 (R)
unnamed: D3.1 (K), R9.2
unnamed: R5.2, RV1.4
unnamed: C3.1, RV1.5, SW1.2 (COM_1), U3.2 (TR), U3.6 (THR)
unnamed: R3.2, S2.3, S2.4, SW1.3 (NO_1)
unnamed: C2.1, U1.5 (CV)
unnamed: C1.1, R1.2, S1.1, S1.2, U1.2 (TR), U1.6 (THR)
unnamed: C4.1, U3.5 (CV)
unnamed: R4.2, R5.1, U3.7 (DIS)
unnamed: U2.12, U3.3 (Q)

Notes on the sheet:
Button up: 2 & 1 / 5 & 4 Button down: 2 & 3 / 5 & 6
CLOCK SPEED
RESET
CLOCK/~{CLOCK}/HALT
MANUAL CONTROL

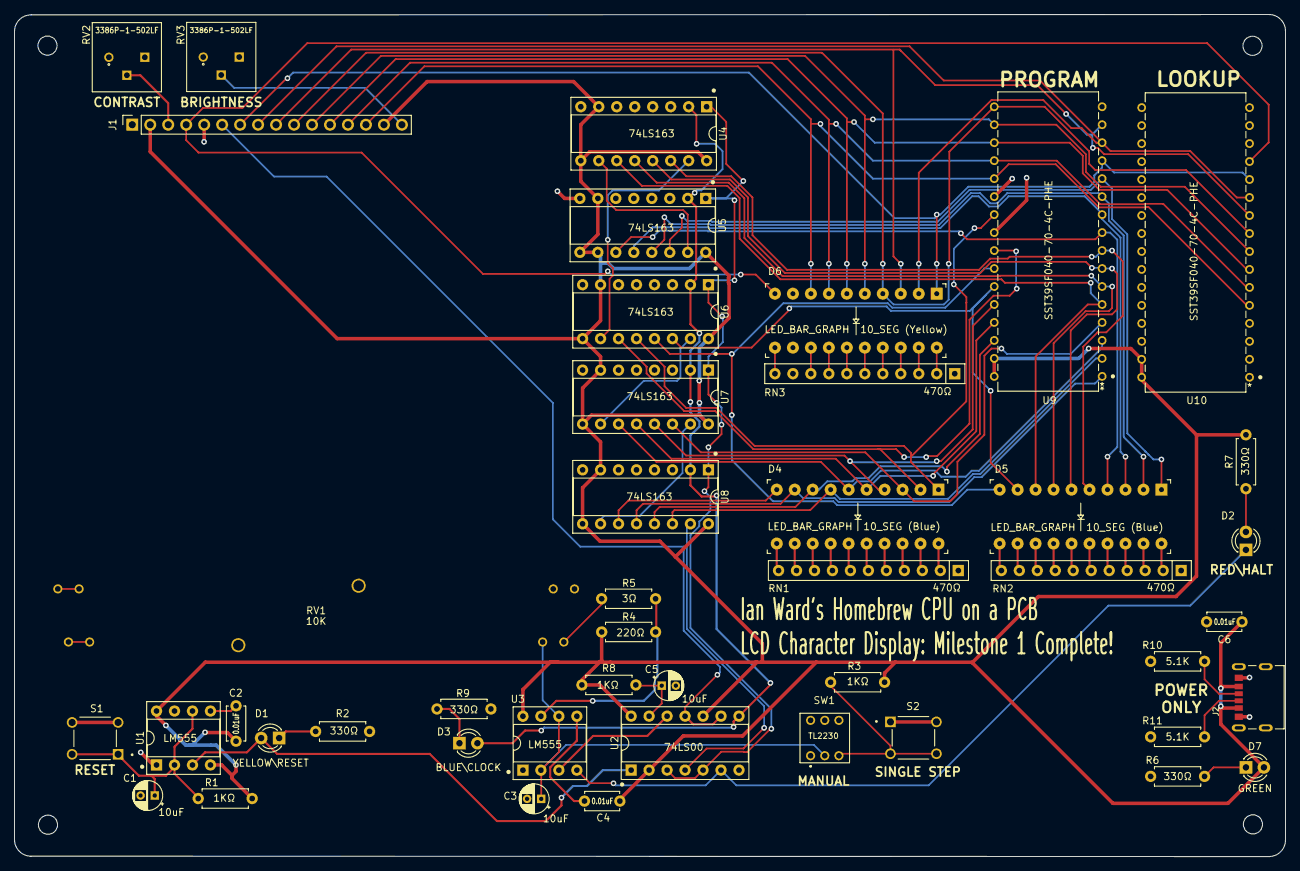
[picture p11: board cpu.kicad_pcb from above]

Board: 2 copper layers, 179.6 x 119.0 mm, 49 parts (0 on the bottom side), 87 nets.

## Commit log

2024-03-07 Initial commit before pusing to GitHub repo.
    [bar_graph.kicad_sch, clock.kicad_sch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]
2024-03-14 Adjusted positions of resistors for LEDs. Added Lutzcraft logo to project footprint library.
    [cpu.kicad_pcb]
2024-03-14 Commit to be safe.
    [cpu.kicad_pcb]
2024-03-15 Modofied power flags and other minor edits.
    [clock.kicad_sch, cpu.kicad_pcb, cpu.kicad_sch]
2024-03-17 Changed out USB connector for new power-only version with fewer pins. Generated new gerber/drill files.
    [clock.kicad_sch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]
2024-03-18 Added *copy.kicad_sch and *copy.kicad_pcb to .gitignore.
2024-03-18 Updated front/back boards images. Added missing 3D model for RV2 and RV3.
    [cpu.kicad_pcb]
2024-03-21 Updated symbols/footprint for USB and 5K Trimmer Pots.
    [clock.kicad_sch, cpu.kicad_pcb, cpu.kicad_sch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]
2024-03-21 Updated image of back of board.
2024-03-21 Final changes around adding BOM to README.md
    [bar_graph.kicad_sch, clock.kicad_sch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]
2024-03-22 Updated BOM XLSX and added BOM to README.md.
    [homebrew_cpu_BOM.xlsx]
2024-03-22 Got rid of track connecting grounds on right side of RN1 and RN2. Regenerated gerber/drill files. Updated board front image.
    [cpu-B_Courtyard.gbr, cpu-B_Cu.gbl, cpu-B_Fab.gbr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]
2024-03-22 Updated board front image to get rid opf highlight on LCD.
2024-03-27 Updated README.md about no I2C adapter on LCD 2004.
2024-03-29 Updated README.md with Ian's suggestions and added calrity to the BOM comments.
2024-03-29 Adding bar_graph.kicad_sch that was previously deleted by accident.
    [bar_graph.kicad_sch]
2024-03-29 Adding PDF of schematic for non-Kicad users.
2024-03-29 Minor edits.
    [bar_graph.kicad_sch]
2024-03-29 Added 'LCD Character Display: Milestone 1 Complete!' to front silkscreen.
    [cpu.kicad_pcb]
2024-10-02 V1.1-last Kicad v7 version
    [bar_graph.kicad_sch, clock.kicad_sch, cpu.kicad_pcb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]
2024-10-02 First KiCad v8 version.All ERC/DRC errors/warnings fixed - had to fix nets on left end of audio potentiometer so that they match. Weird.
    [bar_graph.kicad_sch, clock.kicad_sch, cpu.kicad_pcb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]
